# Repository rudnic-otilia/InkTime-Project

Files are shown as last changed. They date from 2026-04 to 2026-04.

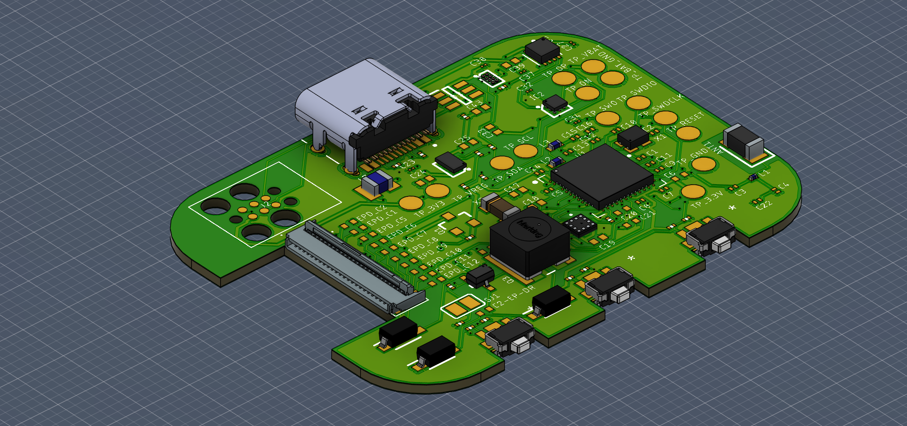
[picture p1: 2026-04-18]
Images/pcb.png

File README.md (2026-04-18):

# InkTime

Smartwatch open-source bazat pe nRF52840, cu display e-paper.

## Diagramă Bloc
Diagram

## BOM (Bill of Materials)

## Componente principale

| Referinta | Componenta | Descriere | Package | Cantitate | JLCPCB / LCSC | Datasheet |
|---|---|---|---|---|---|---|
| U1 | NRF52840-QIAA-R | MCU principal + BLE 5.0 + USB nativ | aQFN-73 (7×7mm) | 1 | [C190794](https://jlcpcb.com/partdetail/NordicSemicon-NRF52840_QIAAR/C190794) | [Datasheet](https://infocenter.nordicsemi.com/pdf/nRF52840_PS_v1.7.pdf) |
| IC1 | BQ25180YBGR | Charger LiPo cu power-path, I2C | DSBGA-8 (1.6×1.1mm) | 1 | [C3682423](https://jlcpcb.com/partdetail/TexasInstruments-BQ25180YBGR/C3682423) | [Datasheet](https://www.ti.com/lit/ds/symlink/bq25180.pdf) |
| IC9 | RT6160AWSC | Buck-boost regulator 3.3V, I2C | WLCSP-15 (1.4×2.3mm) | 1 | [C7065276](https://jlcpcb.com/partdetail/RichTek-RT6160AWSC/C7065276) | [Datasheet](https://www.richtek.com/assets/product_file/RT6160A/DS6160A-00.pdf) |
| U3 | MAX17048G+T10 | Fuel gauge baterie LiPo, I2C | DFN-8 (2×2mm) | 1 | [C2682616](https://jlcpcb.com/partdetail/MaximIntegrated-MAX17048GT10/C2682616) | [Datasheet](https://www.analog.com/media/en/technical-documentation/data-sheets/MAX17048-MAX17049.pdf) |
| IC3 | BMA423 | Accelerometru 3-axe + pedometru, I2C | LGA-12 (2×2mm) | 1 | [C189517](https://jlcpcb.com/partdetail/BoschSensortec-BMA423/C189517) | [Datasheet](https://www.lcsc.com/datasheet/C189517.pdf) |
| IC2 | DRV2605YZFR | Haptic driver pentru motor ERM, I2C | DSBGA-9 (1.44×1.44mm) | 1 | [C81079](https://jlcpcb.com/partdetail/TexasInstruments-DRV2605YZFR/C81079) | [Datasheet](https://www.ti.com/lit/ds/symlink/drv2605.pdf) |
| D3 | USBLC6-2SC6Y | Protecție ESD linii USB D+/D- | SOT-23-6 | 1 | [C5310974](https://jlcpcb.com/partdetail/TECHPUBLIC-USBLC62SC6Y/C5310974) | [Datasheet](https://www.st.com/resource/en/datasheet/usblc6-2.pdf) |
| Q3 | SI1308EDL-T1-GE3 | N-channel MOSFET, power gate e-paper | SC-70-3 | 1 | [C10487](https://jlcpcb.com/partdetail/VishayIntertech-SI1308EDLT1GE3/C10487) | [Datasheet](https://www.vishay.com/docs/63587/si1308edl.pdf) |
| Q1 | DMG2305UX-7 | P-channel MOSFET, power switch | SOT-23-3 | 1 | [C252544](https://jlcpcb.com/partdetail/Diodes-DMG2305UXT116/C252544) | [Datasheet](https://www.diodes.com/assets/Datasheets/DMG2305UX.pdf) |
| J4 | KH-TYPE-C-16P | Conector USB-C 16 pini | SMD | 1 | [C2765186](https://jlcpcb.com/partdetail/Kinghelm-KH_TYPEC_16P/C2765186) | [Datasheet](https://www.kinghelm.net/usb-connectors/kh-type-c-16p.html) |
| J1 | 503480-2400 | Conector FPC 0.5mm 24 pini, pentru display e-paper | SMD | 1 | [C262280](https://jlcpcb.com/partdetail/Molex-5034802400/C262280) | [Datasheet](https://www.molex.com/en-us/products/part-detail/503480-2400) |
| J2 | TC2030-IDC | Conector Tag-Connect SWD debug/programare | PCB footprint | 1 | — | [Datasheet](https://www.tag-connect.com/wp-content/uploads/bsk-pdf-manager/TC2030-IDC_1.pdf) |
| ANT1 | 2450AT18B100E | Antenă chip 2.4GHz pentru BLE | SMD | 1 | [C89771](https://jlcpcb.com/partdetail/Johanson-2450AT18B100E/C89771) | [Datasheet](https://www.johansontechnology.com/datasheets/2450AT18B100E/2450AT18B100E.pdf) |
| X1 | X322516MLB4SI | Crystal HFXO 32MHz, 8pF, ±10ppm pentru nRF52840 | SMD 2016 | 1 | [C13738](https://jlcpcb.com/partdetail/YangxingTech-X322516MLB4SI/C13738) | [Datasheet](https://datasheet.lcsc.com/lcsc/2110221730_YXC-X322516MLB4SI_C13738.pdf) |
| X2 | Q13FC13500004 | Crystal LFXO 32.768kHz, 12.5pF, ±20ppm pentru RTC | SMD 3215 | 1 | [C32346](https://jlcpcb.com/partdetail/Epson-Q13FC13500004/C32346) | [Datasheet](https://www.lcsc.com/datasheet/C32346.pdf) |
| SW_UP, SW_DN, SW_ENT | EVP-AKE31A | Butoane tactile SMD | SMD | 3 | [C3669064](https://jlcpcb.com/partdetail/Panasonic-EVPAKE31A/C3669064) | [Datasheet](https://industrial.panasonic.com/cdbs/www-data/pdf/ATV0000/ATV0000CE5.pdf) |
| D2, D4, D5 | MBR0530 | Diodă Schottky 0.5A 30V, circuit drive e-paper | SOD-123 | 3 | [C424058](https://jlcpcb.com/partdetail/onsemi-MBR0530T1G/C424058) | [Datasheet](https://www.onsemi.com/pdf/datasheet/mbr0530t1-d.pdf) |
| L7 | FTC252012SR47MBCA | Inductor 0.47µH pentru DC/DC | 0402 | 1 | [C408368](https://jlcpcb.com/partdetail/C408368) | — |
| L5 | Inductor 68µH | Inductor boost pentru circuit drive e-paper | SMD | 1 | — | — |

---

## Pasive (rezistențe și condensatoare)

| Referință | Valoare | Package | Cantitate | Notă |
|---|---|---|---|---|
| C1, C2, C17, C18 | 12pF | 0201 / 0402 | 4 | Load caps cristale |
| C3, C4 | 1pF | 0201 | 2 | RF matching |
| C5, C7, C8, C12, C19 | 100nF | 0201 / 0402 | 5 | Decoupling MCU |
| C6, C20, C21, C14, C43 | 4.7µF | 0402 | 5 | Bulk decoupling |
| C9 | 820pF | 0201 | 1 | RF matching |
| C11 | 100pF | 0201 | 1 | Decoupling |
| C15 | 1.0µF | 0201 | 1 | Decoupling |
| C16 | 47nF | 0201 | 1 | Decoupling |
| C24, C39 | 10µF | 0402 | 2 | Bulk decoupling |
| C25, C33 | 22µF | 0402 | 2 | Output caps RT6160 |
| C23, C27, C34, C32, C37, C38 | 0.1µF / 1µF | 0201 | 6 | Decoupling PMIC |
| C29, C30, C31, C42 | 1µF / 0.1µF | 0201 | 4 | Decoupling diverși |
| C1-EP-DR | 10µF | 0402 | 1 | Circuit drive EPD |
| C2-EP-DR | 4.7µF/25V | 0402 | 1 | Circuit drive EPD |
| EPD_C1...C12 | 1µF/50V, 0.1µF/50V | 0402 | 10 | Condensatoare display |
| R17, R18 | 3K3 | 0201 | 2 | Pull-up I2C |
| R5, R7, R8, R9, R_PWR_EPD, R2_EP_DR | 10K | 0201 | 6 | Pull-up / bias |
| R1_USB, R2_USB | 5K1 | 0201 | 2 | CC pins USB-C |
| R_TYPE_SEL | 2.2Ω | 0201 | 1 | Selecție tip charger |
| R1_EP_DR | 0.47Ω | 0201 | 1 | Sense rezistor EPD |
| R2, R3, R4 | 0Ω | 0201 | 3 | Jumperi / DNP |
| L1 | 3.9nH | 0201 | 1 | RF matching |
| L2 | 10µH | 0402 | 1 | DC/DC inductor MCU |
| L3 | 15nH | 0402 | 1 | RF matching |

---

# Descriere Hardware

## MCU — nRF52840

Microcontrollerul principal este nRF52840 de la Nordic Semiconductor, un ARM Cortex-M4 la 64 MHz cu BLE 5.0 si USB nativ integrate. Are 1 MB Flash si 256 KB RAM. A fost ales pentru ca include tot ce e necesar intr-un singur chip: procesor, radio BLE si USB, ceea ce simplifica mult designul unui smartwatch.

Are doua cristale externe obligatorii: unul de 32 MHz pentru BLE si USB, si unul de 32.768 kHz pentru ceasul in timp real (RTC) care mentine ora cand dispozitivul doarme.

Consumul in deep sleep este sub 2 uA, ceea ce il face potrivit pentru un dispozitiv cu baterie mica.

---

## Magistrala I2C

Majoritatea componentelor comunica cu MCU-ul prin I2C pe pinii P0.06 (SDA) si P0.07 (SCL), cu rezistente pull-up de 3.3K. Fiecare componenta are o adresa unica:

| Componenta | Rol | Adresa |
|---|---|---|
| BQ25180 | Charger baterie | 0x6A |
| RT6160 | Regulator 3.3V | 0x75 |
| MAX17048 | Nivel baterie | 0x36 |
| BMA423 | Accelerometru | 0x18 |
| DRV2605 | Motor vibratii | 0x5A |

---

## Display E-Paper

Display-ul de 1.54" (200x200 pixeli) este conectat prin SPI (SCK pe P0.02, MOSI pe P0.03, plus pini de control CS/DC/RST/BUSY). Avantajul e-paper-ului este ca nu consuma energie cand imaginea sta pe loc — consuma doar la refresh.

Alimentarea display-ului este controlata printr-un MOSFET (P1.01) care il opreste complet intre refresh-uri. Se face un refresh partial o data pe minut pentru a actualiza ora, si un full refresh mai rar pentru a elimina ghosting-ul.

---

## Alimentare

Lantul de alimentare functioneaza asa: USB-C (5V) → BQ25180 (incarca bateria si alimenteaza sistemul) → RT6160 (converteste tensiunea bateriei la 3.3V fix) → toate componentele.

BQ25180 are un circuit de power-path, adica sistemul functioneaza si fara baterie daca e conectat la USB. MAX17048 masoara nivelul bateriei si trimite o intrerupere la MCU cand bateria e aproape descarcata.

Pe liniile USB exista o dioda ESD (USBLC6-2SC6Y) care protejeaza circuitul impotriva descarcarilor electrostatice.

---

## Senzori si periferice

**BMA423** — accelerometru cu pedometru hardware integrat. Numara pasii independent, fara sa trezeasca MCU-ul. Trezeste MCU-ul printr-o intrerupere pe P0.08 cand detecteaza miscare sau un anumit numar de pasi.

**DRV2605** — driver pentru motorul de vibratie. MCU-ul ii trimite prin I2C un ID de efect, iar DRV2605 il executa autonom din biblioteca sa de 123 de efecte stocate intern.

**Butoane** — trei butoane (Sus/Jos/Enter) conectate active-low la GND pe pinii P0.13, P0.14 si P1.00. Pot trezi MCU-ul din sleep.

---

## Consum estimat

| Stare | Curent | Timp/zi |
|---|---|---|
| Deep sleep | ~8 uA | ~24h |
| Refresh display (1x/min) | ~8 mA | ~60s total |
| Notificare (BLE + display + vibratii) | ~15 mA | ~100s total |

Total estimat: ~2 mAh/zi → pe o baterie de 250 mAh rezulta o autonomie teoretica de peste 100 de zile. In practica, cu pierderile reale, targetul este de 30 de zile conform specificatiilor proiectului.

# Pini nRF52840 folositi

## I2C — P0.06 (SDA) si P0.07 (SCL)

Acesti doi pini sunt folositi de toate componentele care comunica prin I2C: charger-ul BQ25180,
regulatorul RT6160, fuel gauge-ul MAX17048, accelerometrul BMA423 si driverul haptic DRV2605.
Sunt pini de uz general cu suport hardware I2C si sunt plasati convenabil in schema pentru
rutarea PCB-ului. Pull-up-urile de 3.3K sunt necesare pentru ca I2C are iesiri open-drain.

## SPI — P0.02 (SCK), P0.03 (MOSI), P0.05 (CS)

Folositi pentru comunicatia cu display-ul e-paper. SPI a fost ales in loc de I2C pentru display
deoarece este mult mai rapid, important la refresh-ul imaginii. CS (chip select) pe P0.05
activeaza display-ul doar cand MCU-ul vrea sa ii trimita date.

## Pini de control display — P0.15 (DC), P0.16 (RST), P0.17 (BUSY)

- **DC** (Data/Command): ii spune display-ului daca ce primeste este o comanda sau date de imagine
- **RST** (Reset): reseteaza display-ul la pornire sau dupa o eroare
- **BUSY**: display-ul tine acest pin activ cat timp proceseaza un refresh; MCU-ul asteapta sa
  se elibereze inainte sa trimita date noi

## Power gate display — P1.01

Controleaza MOSFET-ul care opreste alimentarea display-ului cand nu e folosit. Implicit OFF la
reset, activat doar in timpul unui refresh. Economiseste energie intre actualizari.

## Intreruperi

- **P0.08 — BMA423 INT1**: trezeste MCU-ul din deep sleep la detectia de miscare sau pas.
  Folosit ca sursa principala de wake-up pentru activitate fizica.
- **P1.08 — BMA423 INT2**: intrerupere secundara pentru evenimente avansate ale accelerometrului.
- **P0.10 — MAX17048 ALRT**: MCU-ul este notificat cand bateria scade sub un prag configurat,
  pentru a afisa avertismentul de baterie descarcata.
- **P0.11 — BQ25180 /INT**: notifica MCU-ul la evenimente de incarcare (USB conectat/deconectat,
  incarcare completa, eroare).

## Haptic enable — P0.12

Controleaza pinul EN al DRV2605. Cand nu e niciun eveniment haptic, acest pin e LOW si driverul
consuma sub 1 uA. MCU-ul il ridica la HIGH doar inainte sa trimita o comanda de vibratie.

## Butoane — P0.13, P0.14, P1.00

- **P0.13** — buton Sus
- **P0.14** — buton Jos
- **P1.00** — buton Enter / Esc

Toti trei sunt configurati cu pull-up intern si wake-on-low, adica o apasare de buton trezeste
MCU-ul direct din deep sleep fara consum suplimentar.

## USB — USBDP / USBDM (D+ / D-)

Pini dedicati USB ai nRF52840, rutati diferential la conectorul USB-C prin dioda ESD. Folositi
pentru programarea firmware-ului si optional pentru comunicatie cu PC-ul.

## SWD — SWDIO, SWDCLK, nRESET

Pini dedicati de debug si programare, conectati la conectorul TC2030. Folositi cu un programator
J-Link pentru a incarca firmware-ul si pentru debugging in timp real.

# Design Decisions — DRC Approved Errors

DRC-ul a returnat 0 erori si 85 aprobate. Motivele aprobarii:

- **Overlap (35) si Board Outline Clearance (40)**: provin din pozitia butoanelor, care a fost
  stabilita ca cerinta de proiect si nu poate fi modificata.

- **Copper Clearance (9)**: vias-uri care se intersecteaza

- **Copper - Restrict Clearance (1)**: zona restrictionata definita intentionat in jurul antenei
  BLE pentru izolarea ground plane-ului, conform recomandarilor Nordic Semiconductor.

Apache 2.0 — vezi [LICENSE](LICENSE)

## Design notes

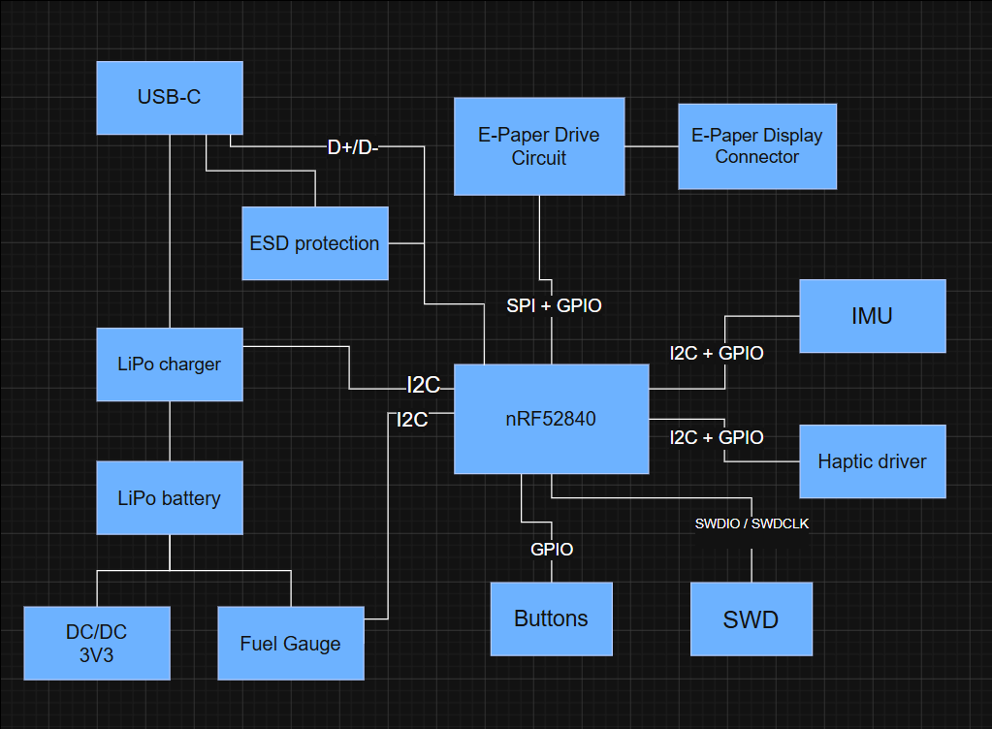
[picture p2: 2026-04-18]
Images/Diagram.png

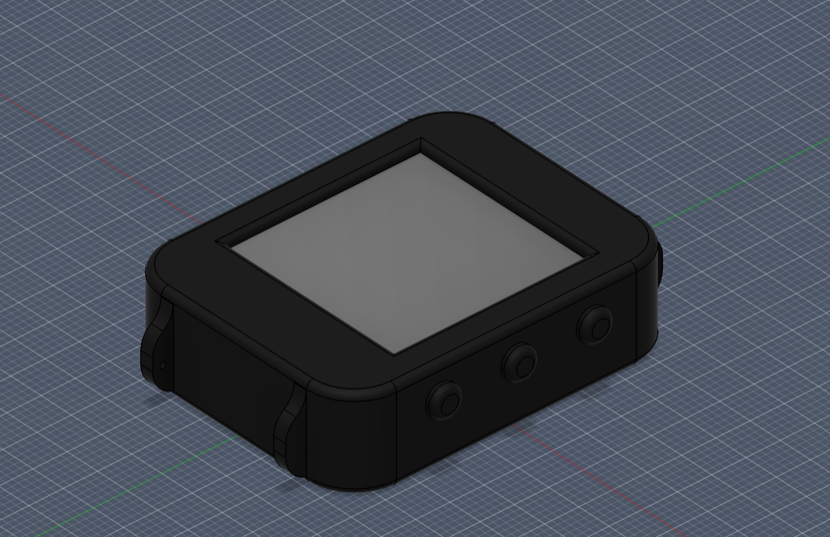
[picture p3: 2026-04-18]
Images/case.png

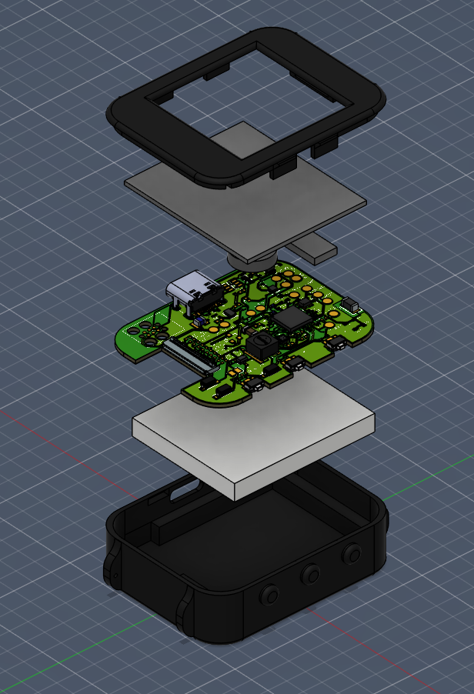
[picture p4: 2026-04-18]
Images/case-exploded-view.png

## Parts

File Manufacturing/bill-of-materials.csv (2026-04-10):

Reference Designators | Quantity | Description | Package | Value | Manufacturer | Manufacturer Part Number | Vendor | Vendor Part Number | Top/Bottom
 | 1 | PCB Board | Board
ANT1 | 1 | Antennas 2.45GHz ANTENNA | 2450AT18B100E_ANTC3216X140N | 2450AT18B100E |  |  |  |  | Top
C1, C2 | 2 | Generic chip capacitor | NORDIC_NRF_3_RESC0201_L | 12pF |  |  |  |  | Top
C1-EP-DR | 1 | Generic chip capacitor | NORDIC_NRF_3_RESC0402_L | 10uF |  |  |  |  | Top
C2-EP-DR | 1 | Generic chip capacitor | NORDIC_NRF_3_RESC0402_L | 4.7uF/25V |  |  |  |  | Top
C3, C4 | 2 | Generic chip capacitor | NORDIC_NRF_3_RESC0201_L | 1pF |  |  |  |  | Top
C5, C7, C8, C12 | 4 | Generic chip capacitor | NORDIC_NRF_3_RESC0201_L | 100nF |  |  |  |  | Top
C6, C20, C21 | 3 | Generic chip capacitor | NORDIC_NRF_3_RESC0402_L | 4.7uF |  |  |  |  | Top
C9 | 1 | Generic chip capacitor | NORDIC_NRF_3_RESC0201_L | 820pF |  |  |  |  | Top
C10, C13, C22 | 3 | Generic chip capacitor | NORDIC_NRF_3_RESC0201_L | N.C. |  |  |  |  | Top
C11 | 1 | Generic chip capacitor | NORDIC_NRF_3_RESC0201_L | 100pF |  |  |  |  | Top
C14 | 1 | Generic chip capacitor | NORDIC_NRF_3_RESC0201_L | 4.7uF |  |  |  |  | Top
C15 | 1 | Generic chip capacitor | NORDIC_NRF_3_RESC0201_L | 1.0uF |  |  |  |  | Top
C16 | 1 | Generic chip capacitor | NORDIC_NRF_3_RESC0201_L | 47nF |  |  |  |  | Top
C17, C18 | 2 | 0402 (1005 Metric) | PERFECT_0402_0402 | 12pF |  |  |  |  | Top
C19 | 1 | 0402 (1005 Metric) | PERFECT_0402_0402 | 100nF |  |  |  |  | Top
C23, C27, C34 | 3 | Check availability | CAPC0201X13N | 0.1uF |  |  |  |  | Top
C24, C39 | 2 | 0402 (1005 Metric) | PERFECT_0402_0402 | 10uF |  |  |  |  | Top
C25, C33 | 2 | 0402 (1005 Metric) | PERFECT_0402_0402 | 22uF |  |  |  |  | Top
C29, C30, C31 | 3 | Check availability | GRM011R60J152KE01L_1_0201 | 1uF |  |  |  |  | Top
C32, C37, C38 | 3 | Check availability | CAPC0201X13N | 1uF |  |  |  |  | Top
C42 | 1 | Check availability | GRM011R60J152KE01L_1_0201 | 0.1uF |  |  |  |  | Top
C43 | 1 | 0402 (1005 Metric) | PERFECT_0402_0402 | 4.7uF |  |  |  |  | Top
D2, D4, D5 | 3 | ON SEMICONDUCTOR - MBR0530 - DIODE, SCHOTTKY, 0.5A, 30V, SOD-123 | SOD3716X135N | MBR0530 |  |  |  |  | Top
D3 | 1 | Low Cap. ESD Protection Auto SOT-23-6 STMicroelectronics USBLC6-2SC6Y, Dual Uni-Directional TVS Diode Array, 6-Pin SOT-23 | SOT95P280X145-6N | USBLC6-2SC6Y |  |  |  |  | Top
EPD_C1, EPD_C2, EPD_C6, EPD_C7, EPD_C8, EPD_C9, EPD_C10, EPD_C11, EPD_C12 | 9 | Generic chip capacitor | NORDIC_NRF_3_RESC0402_L | 1uF/50V |  |  |  |  | Top
EPD_C5 | 1 | Generic chip capacitor | NORDIC_NRF_3_RESC0402_L | 0.1uF/50V |  |  |  |  | Top
IC1 | 1 | Charger IC Lithium Ion/Polymer, Lithium Iron Phosphate 8-DSBGA (1.6x1.1) | BQ25180YBGR_BGA8C40P2X4_100X155X50 | BQ25180YBGR |  |  |  |  | Top
IC2 | 1 | Haptic Driver for ERM/LRA with Built-In Library and Smart Loop Architecture | DRV2605YZFR_BGA9C50P3X3_144X144X62 | DRV2605YZFR |  |  |  |  | Top
IC3 | 1 | Accelerometers Triaxial low-g 12bit Acceleration Sensor | BMA423_BMA423 | BMA423 |  |  |  |  | Top
IC9 | 1 | Buck-Boost Regulator Positive Output Step-Up/Step-Down I2C DC-DC Controller IC 15-WL-CSP (BSC) (1.4x2.3) | RT6160AWSC_BGA15C40P3X5_140X230X60 | RT6160AWSC |  |  |  |  | Top
J1 | 1 | FFC & FPC Connectors 0.5mm FPC RA SMT Dual Contact 24Ckt | 503480-2400_5034802400 | 503480-2400 |  |  |  |  | Top
J2 | 1 | CABLE ADAPTER 6 POS | TC2030-IDC_TC2030IDC | TC2030-IDC |  |  |  |  | Top
J4 | 1 | Check availability | KINGHELM_KH-TYPE-C-16P | KH-TYPE-C-16P |  |  |  |  | Top
L1 | 1 | Generic chip inductor | NORDIC_NRF_2_RESC0201_L | 3.9nH |  |  |  |  | Top
L2 | 1 | Generic chip inductor | NORDIC_NRF_2_RESC0402_L | 10uH |  |  |  |  | Top
L3 | 1 | Generic chip inductor | NORDIC_NRF_2_RESC0402_L | 15nH |  |  |  |  | Top
L5 | 1 |  | ESP32_C6_LIBRARY_2_IND_4828-WE-TPC_WRE | 68uH |  |  |  |  | Top
L7 | 1 | SMD / SMT Inductors (Coils), L=0.47?H, L x W x T : | MLP2016SR47MT0S1_INDC2016X100N | FTC252012SR47MBCA |  |  |  |  | Top
Q1 | 1 | P-channel MOSFETs | ESP32_WROVER_SPARKFUN-DISCRETESEMI_SOT23-3 | 20V/4.2A/52mΩ/1.4W |  |  |  |  | Top
Q3 | 1 | MOSFET N-Ch 30V 1.5A TrenchFET SC70 Vishay Si1308EDL-T1-GE3 N-channel MOSFET Transistor, 1.5 A, 30 V, 3-Pin SC-70 | SOT65P210X110-3N | SI1308EDL-T1-GE3 |  |  |  |  | Top
R_PWR_EPD, R2_EP_DR, R5, R7, R8, R9 | 6 | 7.68k 0201 Thin Film Surface Mount Fixed Resistor +/-0.5% 0.031W CPF0201D7K68C1 | CPF0201D7K68C1_0201 | 10K |  |  |  |  | Top
R_TYPE_SEL | 1 | 7.68k 0201 Thin Film Surface Mount Fixed Resistor +/-0.5% 0.031W CPF0201D7K68C1 | CPF0201D7K68C1_0201 | 2.2 |  |  |  |  | Top
R1_EP_DR | 1 | 7.68k 0201 Thin Film Surface Mount Fixed Resistor +/-0.5% 0.031W CPF0201D7K68C1 | CPF0201D7K68C1_0201 | 0.47 |  |  |  |  | Top
R1_USB, R2_USB | 2 | 7.68k 0201 Thin Film Surface Mount Fixed Resistor +/-0.5% 0.031W CPF0201D7K68C1 | CPF0201D7K68C1_0201 | 5K1 |  |  |  |  | Top
R2, R4 | 2 | 7.68k 0201 Thin Film Surface Mount Fixed Resistor +/-0.5% 0.031W CPF0201D7K68C1 | R0201 | 0 |  |  |  |  | Top
R3 | 1 | 7.68k 0201 Thin Film Surface Mount Fixed Resistor +/-0.5% 0.031W CPF0201D7K68C1 | CPF0201D7K68C1_0201 | 0 |  |  |  |  | Top
R17, R18 | 2 | 7.68k 0201 Thin Film Surface Mount Fixed Resistor +/-0.5% 0.031W CPF0201D7K68C1 | CPF0201D7K68C1_0201 | 3K3 |  |  |  |  | Top
SJ1 | 1 | SMD solder JUMPER | JUMPER_SJ |  |  |  |  |  | Top
SW_DN, SW_ENT, SW_UP | 3 |  | SW_EVP-AKE31A_PAN | 2025-10-22_07-23-44_LIBRARY_EVP-AKE31ASW_EVP-AKE31A_PAN |  |  |  |  | Top
TP_3.3V, TP_3V3, TP_BAT_GND, TP_GND, TP_ON, TP_OP, TP_RESET, TP_SCL, TP_SDA, TP_SWDCLK, TP_SWDIO, TP_SWO, TP_VBAT, TP_VREG | 14 | Test pad | HECTOR_WATCH_1_TP20R | HECTOR_WATCH_1_TPTP20R |  |  |  |  | Top
U1 | 1 | nRF52840 | NORDIC_NRF_4_AQFN50P700X700X85_HS-74N | NRF52840_QF |  |  |  |  | Top
U3 | 1 | Check availability | SON50P200X200X80-9N | MAX17048G+T10 |  |  |  |  | Top
X1 | 1 |  | NORDIC_NRF_BT-XTAL_2016_N | 32MHZ |  |  |  |  | Top
X2 | 1 |  | NORDIC_NRF_1_XTAL_3215_N | 32.768kHz |  |  |  |  | Top

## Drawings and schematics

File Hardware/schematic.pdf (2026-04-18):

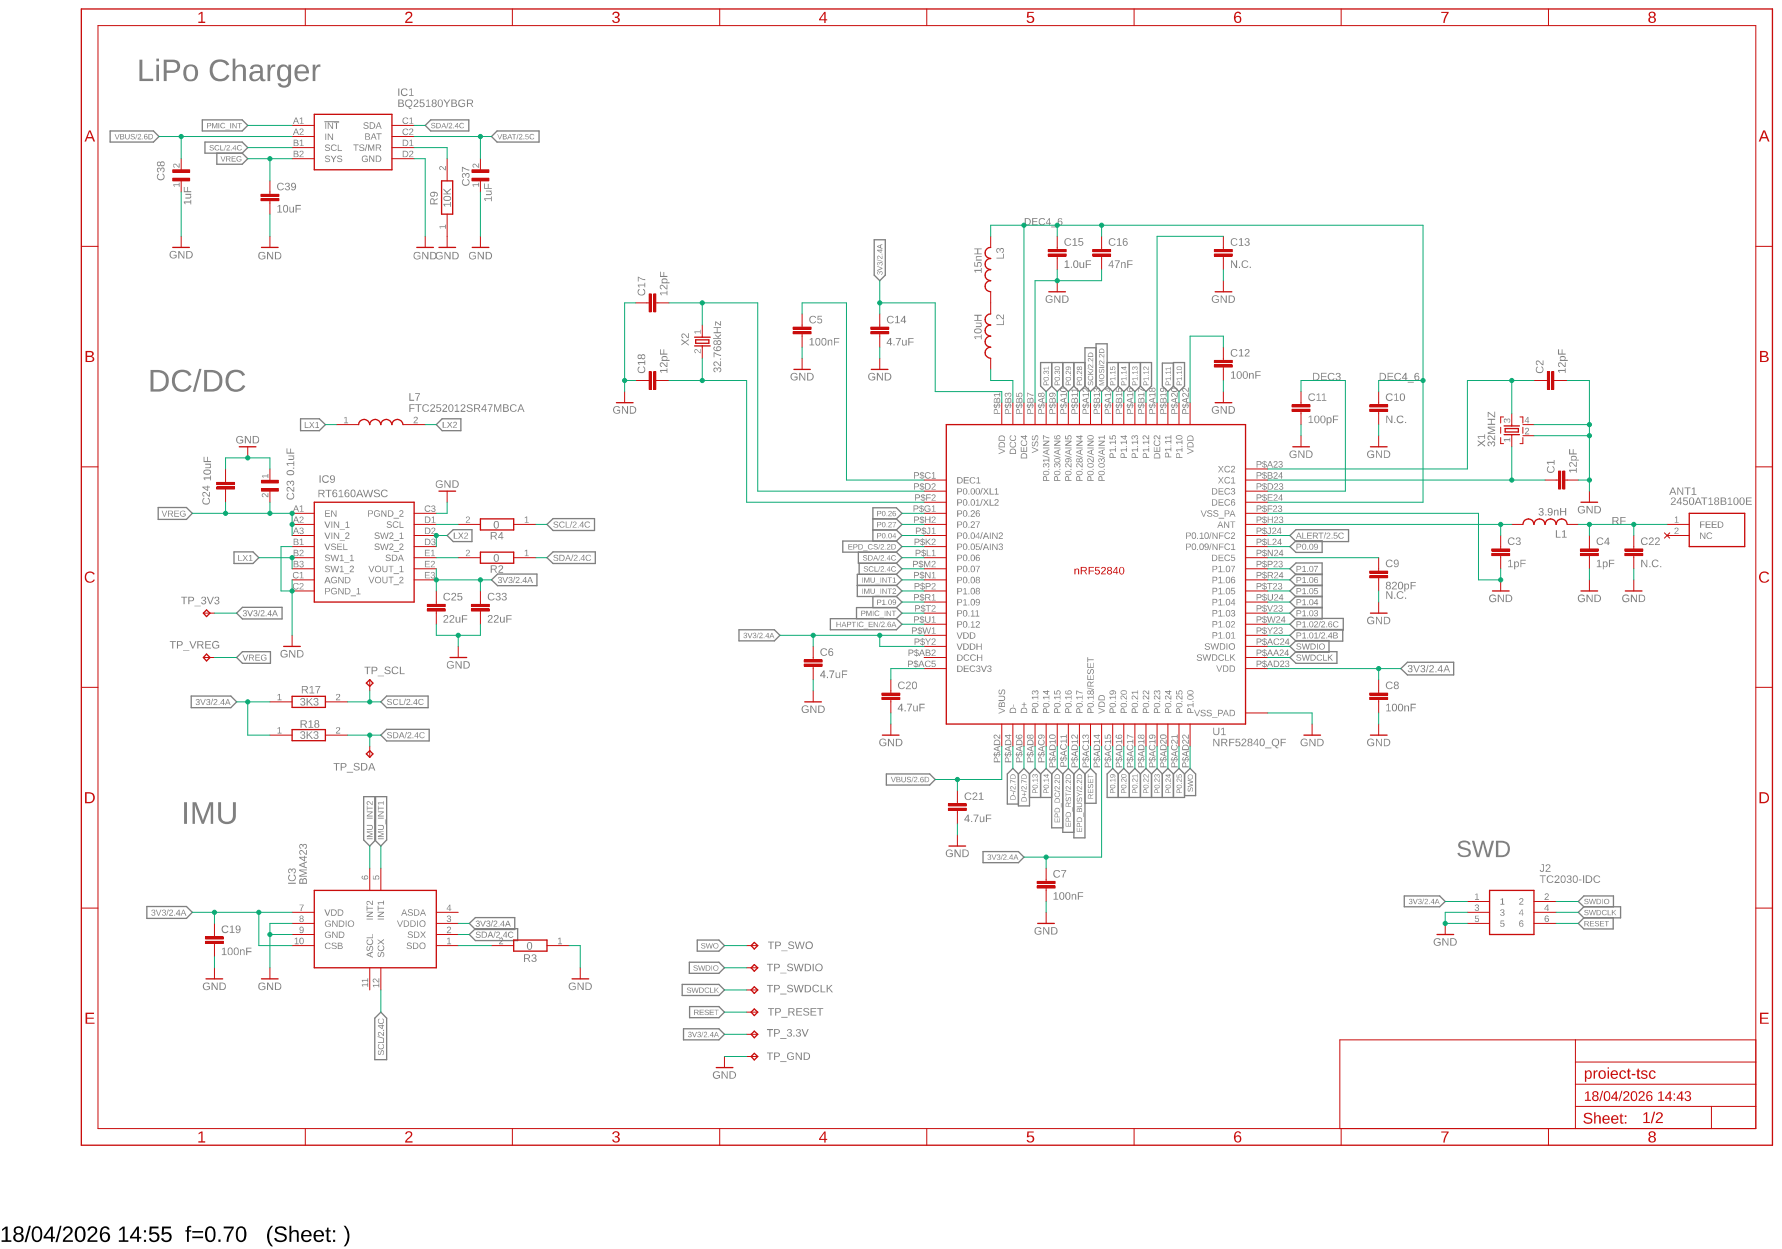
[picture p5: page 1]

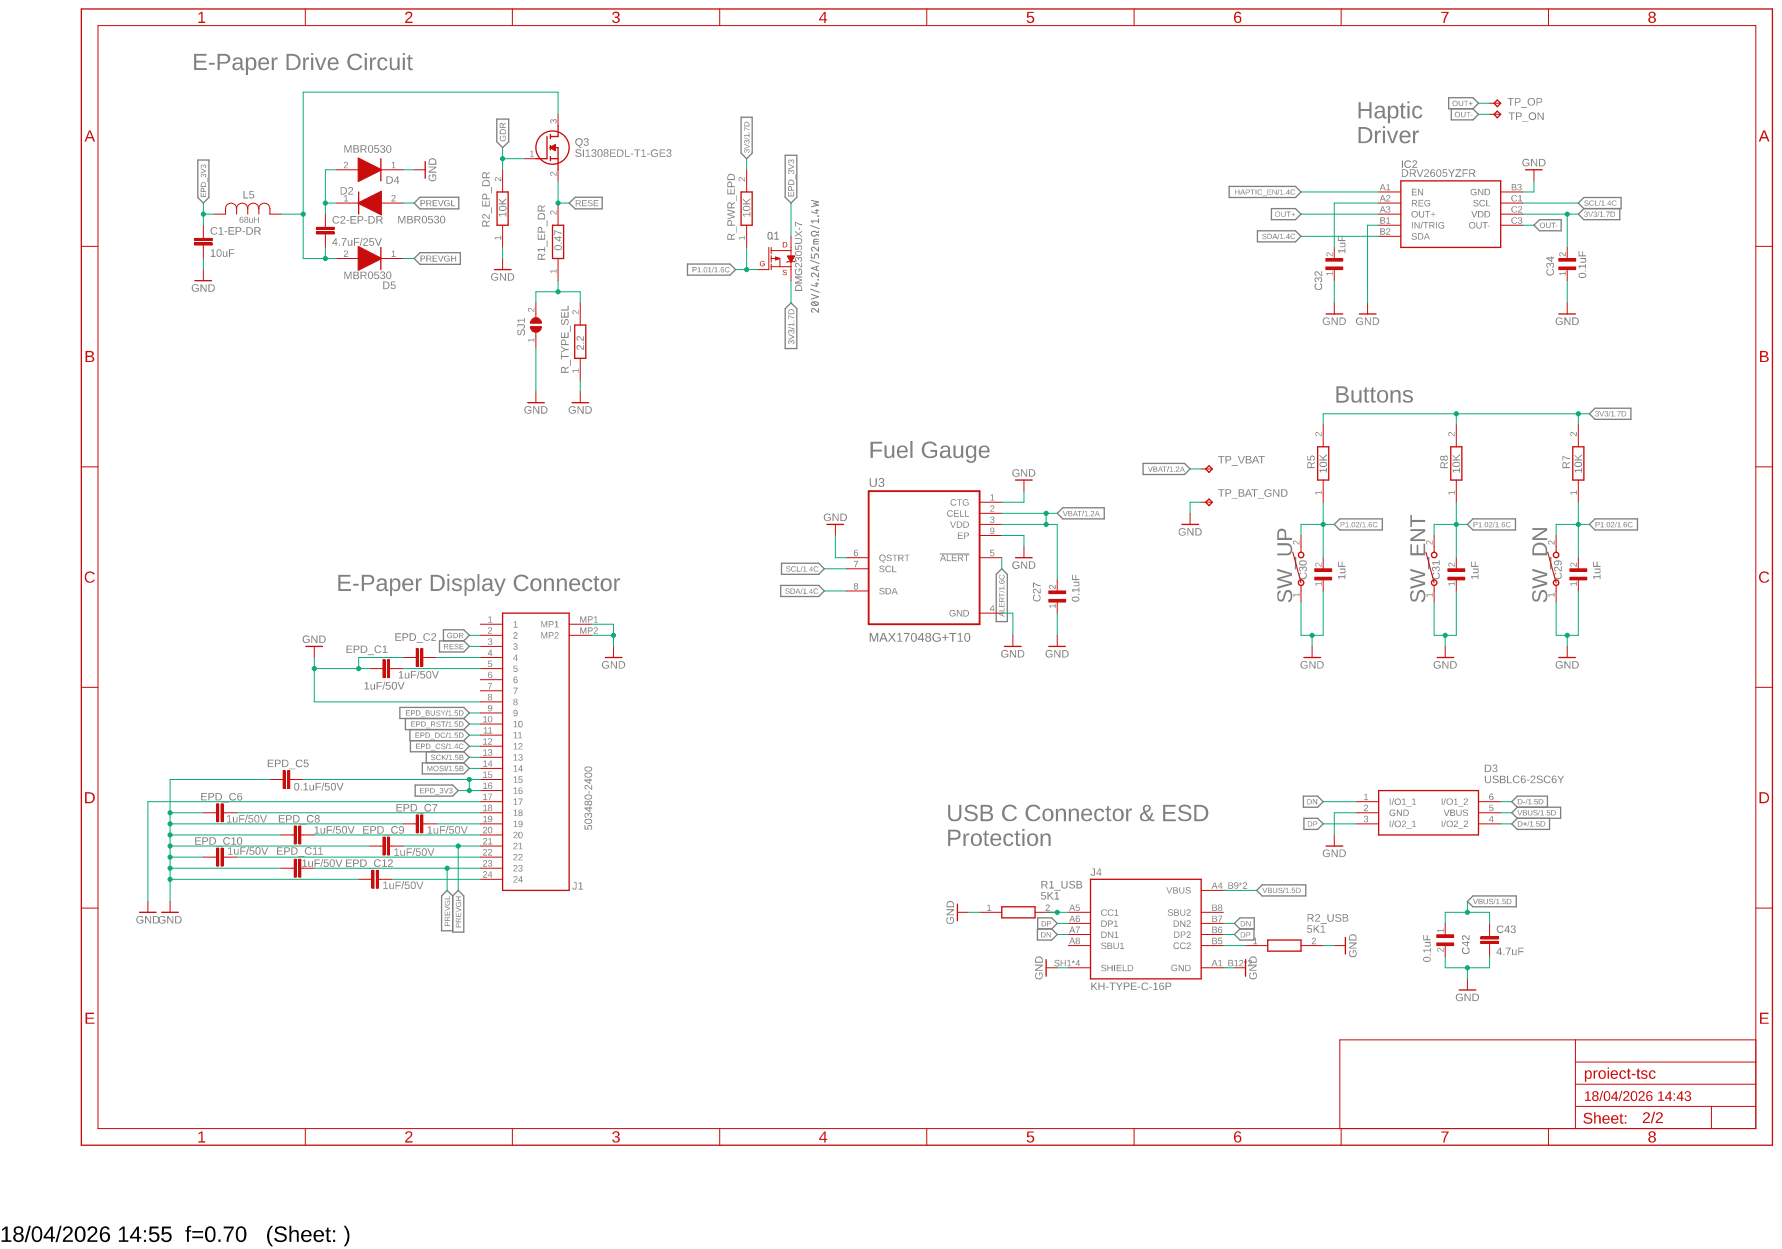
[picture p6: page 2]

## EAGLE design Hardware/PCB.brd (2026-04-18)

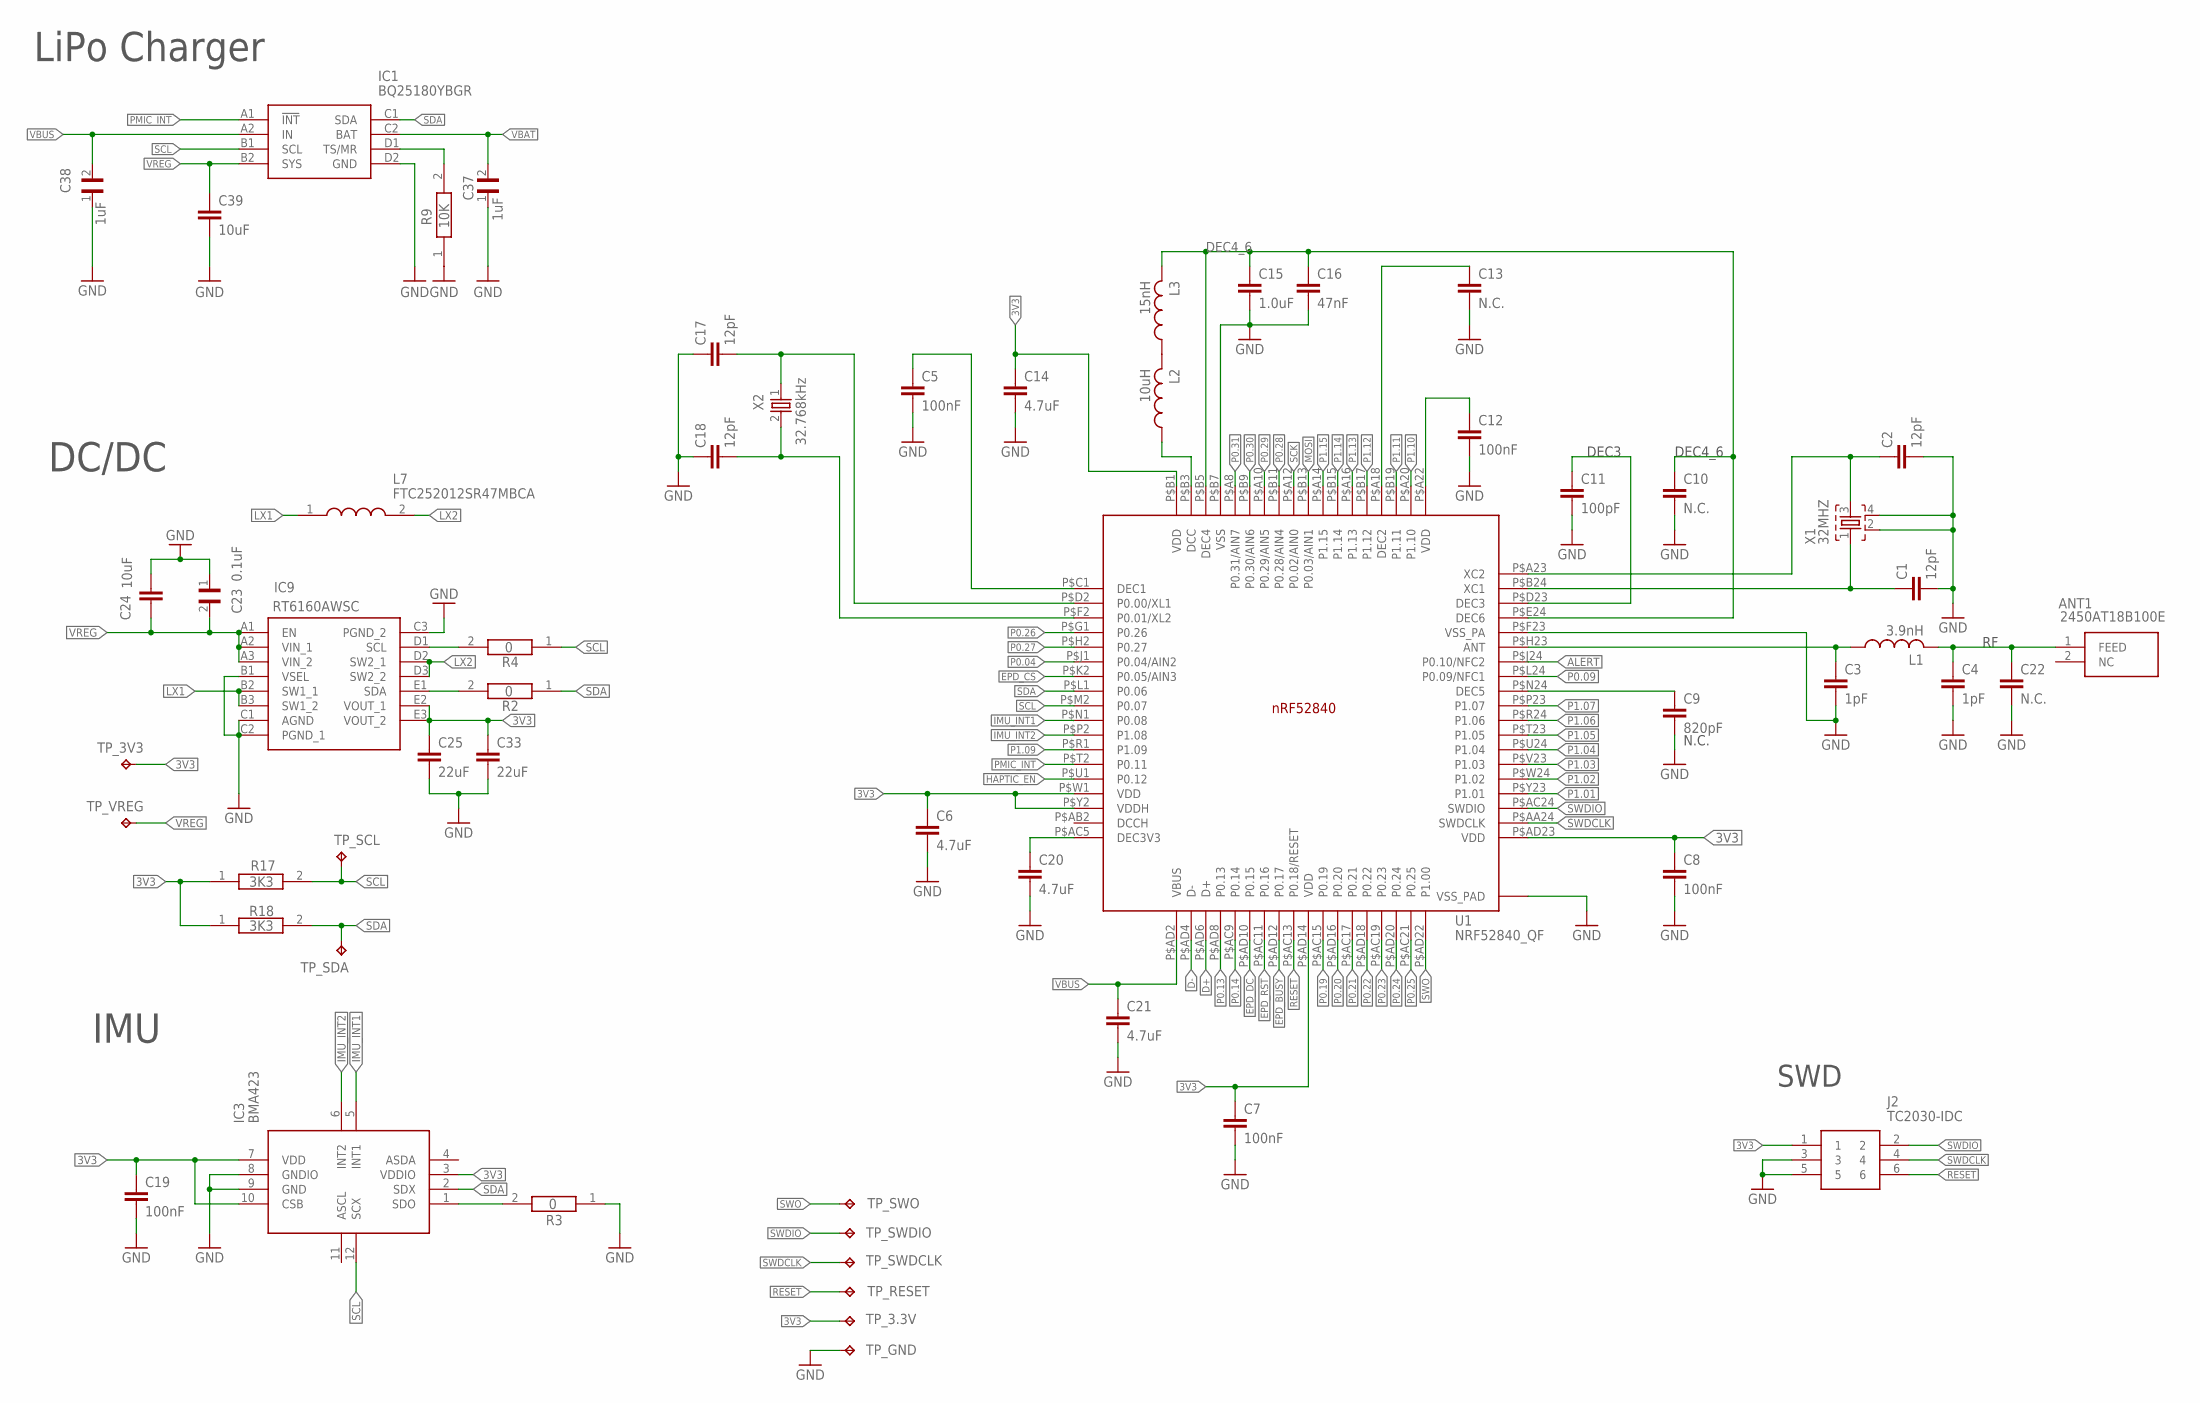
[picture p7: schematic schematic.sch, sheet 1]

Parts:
ANT1: 2450AT18B100E; 2450AT18B100E_ANTC3216X140N
C1, C2: 12pF; NORDIC_NRF_3_RESC0201_L
C3, C4: 1pF; NORDIC_NRF_3_RESC0201_L
C5, C7, C8, C12: 100nF; NORDIC_NRF_3_RESC0201_L
C6, C20, C21: 4.7uF; NORDIC_NRF_3_RESC0402_L
C9: 820pF; NORDIC_NRF_3_RESC0201_L
C10, C13, C22: N.C.; NORDIC_NRF_3_RESC0201_L
C11: 100pF; NORDIC_NRF_3_RESC0201_L
C14: 4.7uF; NORDIC_NRF_3_RESC0201_L
C15: 1.0uF; NORDIC_NRF_3_RESC0201_L
C16: 47nF; NORDIC_NRF_3_RESC0201_L
C17, C18: 12pF; PERFECT_0402_0402
C19: 100nF; PERFECT_0402_0402
C23: 0.1uF; GRM011R60J152KE01L_2_CAPC0201X13N
C24, C39: 10uF; PERFECT_0402_0402
C25, C33: 22uF; PERFECT_0402_0402
C37, C38: 1uF; GRM011R60J152KE01L_2_CAPC0201X13N
IC1: BQ25180YBGR; BQ25180YBGR_BGA8C40P2X4_100X155X50
IC3: BMA423; BMA423_BMA423
IC9: RT6160AWSC; RT6160AWSC_BGA15C40P3X5_140X230X60
J2: TC2030-IDC; TC2030-IDC_TC2030IDC
L1: 3.9nH; NORDIC_NRF_2_RESC0201_L
L2: 10uH; NORDIC_NRF_2_RESC0402_L
L3: 15nH; NORDIC_NRF_2_RESC0402_L
L7: FTC252012SR47MBCA; MLP2016SR47MT0S1_INDC2016X100N
R2, R4: 0; ERA-1AEB3401C_0201
R3: 0; CPF0201D7K68C1_0201
R9: 10K; CPF0201D7K68C1_0201
R17, R18: 3K3; CPF0201D7K68C1_0201
TP_3.3V, TP_3V3: HECTOR_WATCH_1_TPTP20R; HECTOR_WATCH_1_TP20R
TP_GND: HECTOR_WATCH_1_TPTP20R; HECTOR_WATCH_1_TP20R
TP_RESET: HECTOR_WATCH_1_TPTP20R; HECTOR_WATCH_1_TP20R
TP_SCL: HECTOR_WATCH_1_TPTP20R; HECTOR_WATCH_1_TP20R
TP_SDA: HECTOR_WATCH_1_TPTP20R; HECTOR_WATCH_1_TP20R
TP_SWDCLK: HECTOR_WATCH_1_TPTP20R; HECTOR_WATCH_1_TP20R
TP_SWDIO: HECTOR_WATCH_1_TPTP20R; HECTOR_WATCH_1_TP20R
TP_SWO: HECTOR_WATCH_1_TPTP20R; HECTOR_WATCH_1_TP20R
TP_VREG: HECTOR_WATCH_1_TPTP20R; HECTOR_WATCH_1_TP20R
U1: NRF52840_QF; NORDIC_NRF_4_AQFN50P700X700X85_HS-74N
X1: 32MHZ; NORDIC_NRF_BT-XTAL_2016_N
X2: 32.768kHz; NORDIC_NRF_1_XTAL_3215_N

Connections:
3V3: C6.1, C7.1, C8.1, C14.1, C19.1, C25.1, C33.1, IC3.3 (VDDIO), IC3.7 (VDD), IC3.10 (CSB), IC9.E2 (VOUT_1), IC9.E3 (VOUT_2), J2.1, R17.1, R18.1, TP_3.3V.TP, TP_3V3.TP, U1.P$AD14 (VDD), U1.P$AD23 (VDD), U1.P$B1 (VDD), U1.P$W1 (VDD), U1.P$Y2 (VDDH); also elsewhere on the board
ALERT: U1.P$J24 (P0.10/NFC2); also elsewhere on the board
D+: U1.P$AD6 (D+); also elsewhere on the board
D-: U1.P$AD4 (D-); also elsewhere on the board
DEC4_6: C10.1, C15.1, C16.1, L3.2, U1.P$B5 (DEC4), U1.P$E24 (DEC6)
EPD_BUSY: U1.P$AD12 (P0.17); also elsewhere on the board
EPD_CS: U1.P$K2 (P0.05/AIN3); also elsewhere on the board
EPD_DC: U1.P$AD10 (P0.15); also elsewhere on the board
EPD_RST: U1.P$AC11 (P0.16); also elsewhere on the board
GND: C1.2, C2.2, C3.2, C4.2, C5.2, C6.2, C7.2, C8.2, C9.2, C10.2, C11.2, C12.2, C13.2, C14.2, C15.2, C16.2, C17.1, C18.1, C19.2, C20.2, C21.2, C22.2, C23.1, C24.1, C25.2, C33.2, C37.1, C38.1, C39.2, IC1.D2 (GND), IC3.8 (GNDIO), IC3.9 (GND), IC9.B1 (VSEL), IC9.C1 (AGND), IC9.C2 (PGND_1), IC9.C3 (PGND_2), J2.3, J2.5, R3.1, R9.1, TP_GND.TP, U1.P$74 (VSS_PAD), U1.P$75 (VSS_PAD), U1.P$76 (VSS_PAD), U1.P$77 (VSS_PAD), U1.P$78 (VSS_PAD), U1.P$79 (VSS_PAD), U1.P$80 (VSS_PAD), U1.P$81 (VSS_PAD), U1.P$82 (VSS_PAD), U1.P$83 (VSS_PAD), U1.P$84 (VSS_PAD), U1.P$85 (VSS_PAD), U1.P$86 (VSS_PAD), U1.P$87 (VSS_PAD), U1.P$88 (VSS_PAD), U1.P$89 (VSS_PAD), U1.P$90 (VSS_PAD), U1.P$B7 (VSS), U1.P$F23 (VSS_PA), X1.2, X1.4; also elsewhere on the board
HAPTIC_EN: U1.P$U1 (P0.12); also elsewhere on the board
IMU_INT1: IC3.5 (INT1), U1.P$N1 (P0.08)
IMU_INT2: IC3.6 (INT2), U1.P$P2 (P1.08)
LX1: IC9.B2 (SW1_1), IC9.B3 (SW1_2), L7.1
LX2: IC9.D2 (SW2_1), IC9.D3 (SW2_2), L7.2
MOSI: U1.P$B13 (P0.03/AIN1); also elsewhere on the board
unnamed: IC1.D1 (TS/MR), R9.2
unnamed: C11.1, U1.P$D23 (DEC3)
unnamed: IC9.D1 (SCL), R4.2
unnamed: IC9.E1 (SDA), R2.2
unnamed: C18.2, U1.P$F2 (P0.01/XL2), X2.2
unnamed: C17.2, U1.P$D2 (P0.00/XL1), X2.1
unnamed: IC3.1 (SDO), R3.2
unnamed: C5.1, U1.P$C1 (DEC1)
unnamed: L2.1, U1.P$B3 (DCC)
unnamed: L2.2, L3.1
unnamed: C12.1, U1.P$A22 (VDD)
unnamed: C13.1, U1.P$A18 (DEC2)
unnamed: C2.1, U1.P$A23 (XC2), X1.3
unnamed: C1.1, U1.P$B24 (XC1), X1.1
unnamed: C3.1, L1.1, U1.P$H23 (ANT)
unnamed: ANT1.1 (FEED), C4.1, C22.1, L1.2
unnamed: C9.1, U1.P$N24 (DEC5)
unnamed: C20.1, U1.P$AC5 (DEC3V3)
P0.04: U1.P$J1 (P0.04/AIN2)
P0.09: U1.P$L24 (P0.09/NFC1)
P0.13: U1.P$AD8 (P0.13)
P0.14: U1.P$AC9 (P0.14)
P0.19: U1.P$AC15 (P0.19)
P0.20: U1.P$AD16 (P0.20)
P0.21: U1.P$AC17 (P0.21)
P0.22: U1.P$AD18 (P0.22)
P0.23: U1.P$AC19 (P0.23)
P0.24: U1.P$AD20 (P0.24)
P0.25: U1.P$AC21 (P0.25)
P0.26: U1.P$G1 (P0.26)
P0.27: U1.P$H2 (P0.27)
P0.28: U1.P$B11 (P0.28/AIN4)
P0.29: U1.P$A10 (P0.29/AIN5)
P0.30: U1.P$B9 (P0.30/AIN6)
P0.31: U1.P$A8 (P0.31/AIN7)
P1.01: U1.P$Y23 (P1.01); also elsewhere on the board
P1.02: U1.P$W24 (P1.02); also elsewhere on the board
P1.03: U1.P$V23 (P1.03)
P1.04: U1.P$U24 (P1.04)
P1.05: U1.P$T23 (P1.05)
P1.06: U1.P$R24 (P1.06)
P1.07: U1.P$P23 (P1.07)
P1.09: U1.P$R1 (P1.09)
P1.10: U1.P$A20 (P1.10)
P1.11: U1.P$B19 (P1.11)
P1.12: U1.P$B17 (P1.12)
P1.13: U1.P$A16 (P1.13)
P1.14: U1.P$B15 (P1.14)
P1.15: U1.P$A14 (P1.15)
PMIC_INT: IC1.A1 (!INT), U1.P$T2 (P0.11)
RESET: J2.6, TP_RESET.TP, U1.P$AC13 (P0.18/RESET)
SCK: U1.P$A12 (P0.02/AIN0); also elsewhere on the board
SCL: IC1.B1 (SCL), IC3.12 (SCX), R4.1, R17.2, TP_SCL.TP, U1.P$M2 (P0.07); also elsewhere on the board
SDA: IC1.C1 (SDA), IC3.2 (SDX), R2.1, R18.2, TP_SDA.TP, U1.P$L1 (P0.06); also elsewhere on the board
SWDCLK: J2.4, TP_SWDCLK.TP, U1.P$AA24 (SWDCLK)
SWDIO: J2.2, TP_SWDIO.TP, U1.P$AC24 (SWDIO)
SWO: TP_SWO.TP, U1.P$AD22 (P1.00)
VBAT: C37.2, IC1.C2 (BAT); also elsewhere on the board
VBUS: C21.1, C38.2, IC1.A2 (IN), U1.P$AD2 (VBUS); also elsewhere on the board
VREG: C23.2, C24.2, C39.1, IC1.B2 (SYS), IC9.A1 (EN), IC9.A2 (VIN_1), IC9.A3 (VIN_2), TP_VREG.TP

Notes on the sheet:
LiPo Charger
DC/DC
IMU
DEC3
DEC4_6
N.C.
SWD

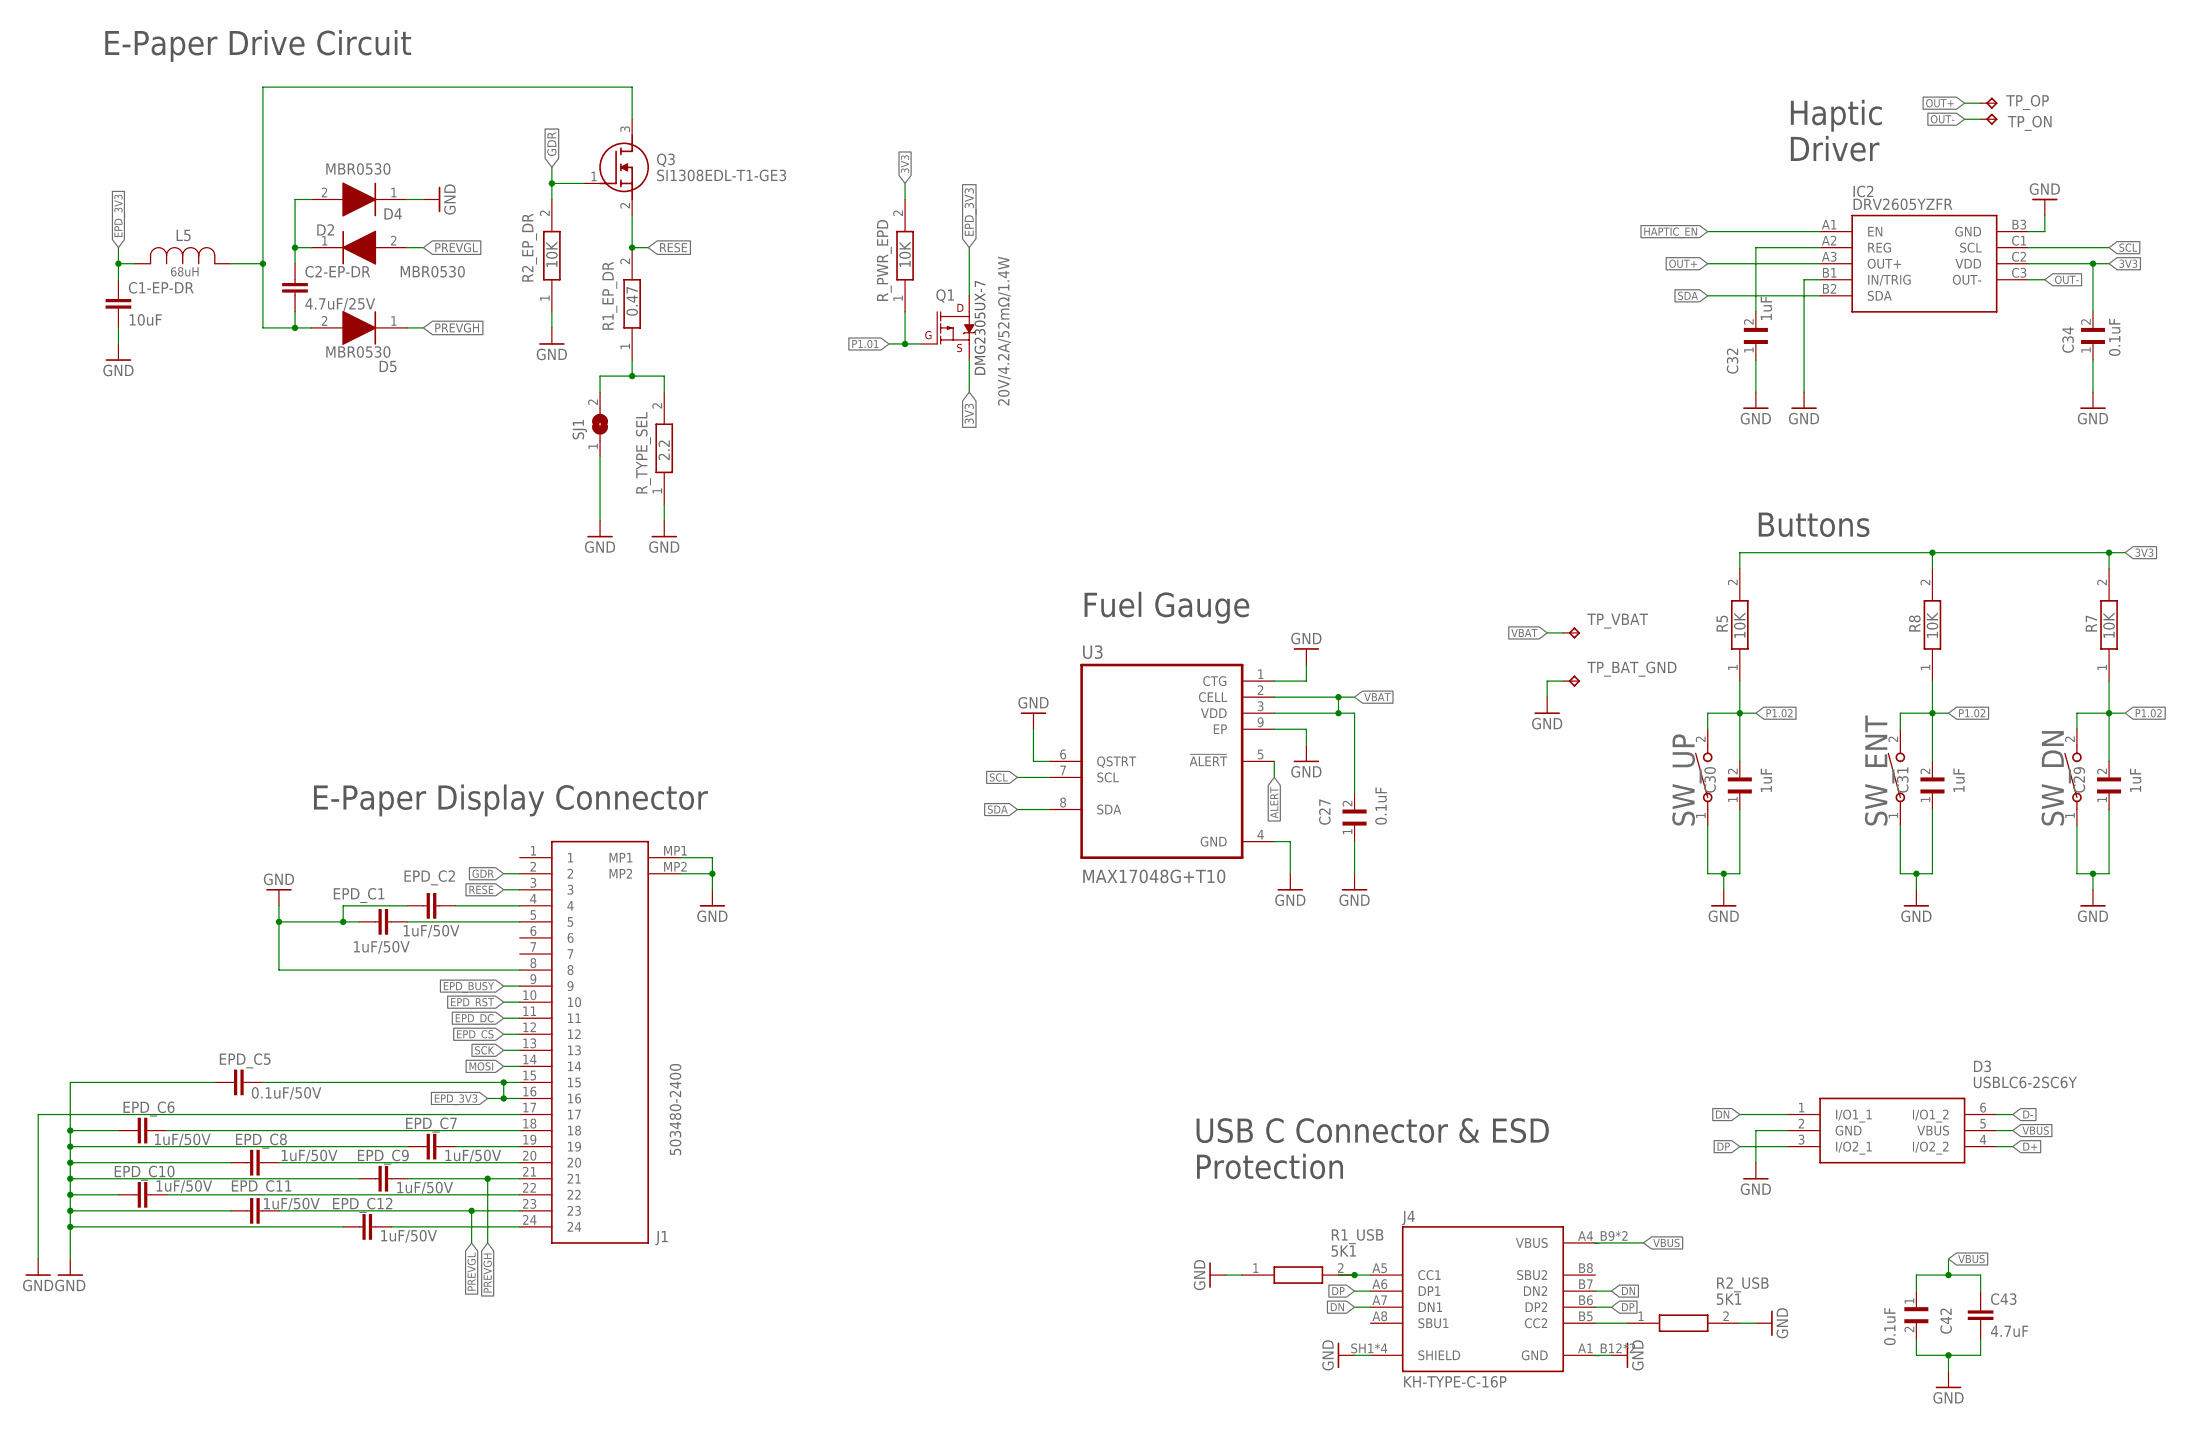
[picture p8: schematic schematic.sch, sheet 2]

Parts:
C1-EP-DR: 10uF; NORDIC_NRF_3_RESC0402_L
C2-EP-DR: 4.7uF/25V; NORDIC_NRF_3_RESC0402_L
C27, C34: 0.1uF; GRM011R60J152KE01L_2_CAPC0201X13N
C29, C30, C31: 1uF; GRM011R60J152KE01L_1_0201
C32: 1uF; GRM011R60J152KE01L_2_CAPC0201X13N
C42: 0.1uF; GRM011R60J152KE01L_1_0201
C43: 4.7uF; PERFECT_0402_0402
D2, D4, D5: MBR0530; ESP32_C6_LIBRARY_5_SOD3716X135N
D3: USBLC6-2SC6Y; ESP32_C6_LIBRARY_3_SOT95P280X145-6N
EPD_C1, EPD_C2, EPD_C6, EPD_C7, EPD_C8, EPD_C9, EPD_C10, EPD_C11, EPD_C12: 1uF/50V; NORDIC_NRF_3_RESC0402_L
EPD_C5: 0.1uF/50V; NORDIC_NRF_3_RESC0402_L
IC2: DRV2605YZFR; DRV2605YZFR_BGA9C50P3X3_144X144X62
J1: 503480-2400; 503480-2400_5034802400
J4: KH-TYPE-C-16P; KH-TYPE-C-16P_KINGHELM_KH-TYPE-C-16P
L5: 68uH; ESP32_C6_LIBRARY_2_IND_4828-WE-TPC_WRE
Q1: 20V/4.2A/52mΩ/1.4W; ESP32_C6_LIBRARY_4_ESP32_C6_LIBRARY_4_ESP32_C6_LIBRARY_4_ES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
Q3: SI1308EDL-T1-GE3; ESP32_C6_LIBRARY_6_SOT65P210X110-3N
R1_EP_DR: 0.47; CPF0201D7K68C1_0201
R1_USB, R2_USB: 5K1; CPF0201D7K68C1_0201
R2_EP_DR, R5, R7, R8: 10K; CPF0201D7K68C1_0201
R_PWR_EPD: 10K; CPF0201D7K68C1_0201
R_TYPE_SEL: 2.2; CPF0201D7K68C1_0201
SJ1: ESP32_C6_LIBRARY_7_JUMPER_SJ
SW_DN: 2025-10-22_07-23-44_LIBRARY_EVP-AKE31ASW_EVP-AKE3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; 2025-10-22_07-23-44_LIBRARY_SW_EVP-AKE31A_PAN
SW_ENT: 2025-10-22_07-23-44_LIBRARY_EVP-AKE31ASW_EVP-AKE3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; 2025-10-22_07-23-44_LIBRARY_SW_EVP-AKE31A_PAN
SW_UP: 2025-10-22_07-23-44_LIBRARY_EVP-AKE31ASW_EVP-AKE3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; 2025-10-22_07-23-44_LIBRARY_SW_EVP-AKE31A_PAN
TP_BAT_GND: HECTOR_WATCH_1_TPTP20R; HECTOR_WATCH_1_TP20R
TP_ON: HECTOR_WATCH_1_TPTP20R; HECTOR_WATCH_1_TP20R
TP_OP: HECTOR_WATCH_1_TPTP20R; HECTOR_WATCH_1_TP20R
TP_VBAT: HECTOR_WATCH_1_TPTP20R; HECTOR_WATCH_1_TP20R
U3: MAX17048G+T10; ESP32_C6_LIBRARY_SON50P200X200X80-9N

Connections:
3V3: C34.2, IC2.C2 (VDD), Q1.2 (S), R5.2, R7.2, R8.2, R_PWR_EPD.2; also elsewhere on the board
ALERT: U3.5 (!ALERT); also elsewhere on the board
D+: D3.4 (I/O2_2); also elsewhere on the board
D-: D3.6 (I/O1_2); also elsewhere on the board
DN: D3.1 (I/O1_1), J4.A7 (DN1), J4.B7 (DN2)
DP: D3.3 (I/O2_1), J4.A6 (DP1), J4.B6 (DP2)
EPD_3V3: C1-EP-DR.1, EPD_C5.2, J1.15, J1.16, L5.2, Q1.3 (D)
EPD_BUSY: J1.9; also elsewhere on the board
EPD_CS: J1.12; also elsewhere on the board
EPD_DC: J1.11; also elsewhere on the board
EPD_RST: J1.10; also elsewhere on the board
GDR: J1.2, Q3.1 (G), R2_EP_DR.2
GND: C1-EP-DR.2, C27.1, C29.1, C30.1, C31.1, C32.1, C34.1, C42.2, C43.2, D3.2 (GND), D4.1 (K), EPD_C1.1, EPD_C2.1, EPD_C5.1, EPD_C6.1, EPD_C7.1, EPD_C8.1, EPD_C9.1, EPD_C10.1, EPD_C11.1, EPD_C12.1, IC2.B1 (IN/TRIG), IC2.B3 (GND), J1.8, J1.17, J1.MP1, J1.MP2, J4.A1_B12 (GND), J4.A12_B1 (GND), J4.SH1 (SHIELD), J4.SH2 (SHIELD), J4.SH3 (SHIELD), J4.SH4 (SHIELD), R1_USB.1, R2_EP_DR.1, R2_USB.2, R_TYPE_SEL.1, SJ1.1, SW_DN.1, SW_ENT.1, SW_UP.1, TP_BAT_GND.TP, U3.1 (CTG), U3.4 (GND), U3.6 (QSTRT), U3.9 (EP); also elsewhere on the board
HAPTIC_EN: IC2.A1 (EN); also elsewhere on the board
MOSI: J1.14; also elsewhere on the board
unnamed: C2-EP-DR.2, D5.2 (A), L5.1, Q3.3 (D)
unnamed: C2-EP-DR.1, D2.1 (K), D4.2 (A)
unnamed: R1_EP_DR.1, R_TYPE_SEL.2, SJ1.2
unnamed: EPD_C2.2, J1.4
unnamed: EPD_C7.2, J1.19
unnamed: EPD_C1.2, J1.5
unnamed: C32.2, IC2.A2 (REG)
unnamed: EPD_C12.2, J1.24
unnamed: J4.B5 (CC2), R2_USB.1
unnamed: EPD_C8.2, J1.20
unnamed: EPD_C10.2, J1.22
unnamed: EPD_C6.2, J1.18
unnamed: J4.A5 (CC1), R1_USB.2
OUT+: IC2.A3 (OUT+), TP_OP.TP
OUT-: IC2.C3 (OUT-), TP_ON.TP
P1.01: Q1.1 (G), R_PWR_EPD.1; also elsewhere on the board
P1.02: C29.2, C30.2, C31.2, R5.1, R7.1, R8.1, SW_DN.2, SW_ENT.2, SW_UP.2; also elsewhere on the board
PREVGH: D5.1 (K), EPD_C9.2, J1.21
PREVGL: D2.2 (A), EPD_C11.2, J1.23
RESE: J1.3, Q3.2 (S), R1_EP_DR.2
SCK: J1.13; also elsewhere on the board
SCL: IC2.C1 (SCL), U3.7 (SCL); also elsewhere on the board
SDA: IC2.B2 (SDA), U3.8 (SDA); also elsewhere on the board
VBAT: C27.2, TP_VBAT.TP, U3.2 (CELL), U3.3 (VDD); also elsewhere on the board
VBUS: C42.1, C43.1, D3.5 (VBUS), J4.A4_B9 (VBUS), J4.A9_B4 (VBUS); also elsewhere on the board

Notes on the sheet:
E-Paper Drive Circuit
DMG2305UX-7
E-Paper Display Connector
Haptic Driver
Buttons
USB C Connector & ESD Protection
Fuel Gauge

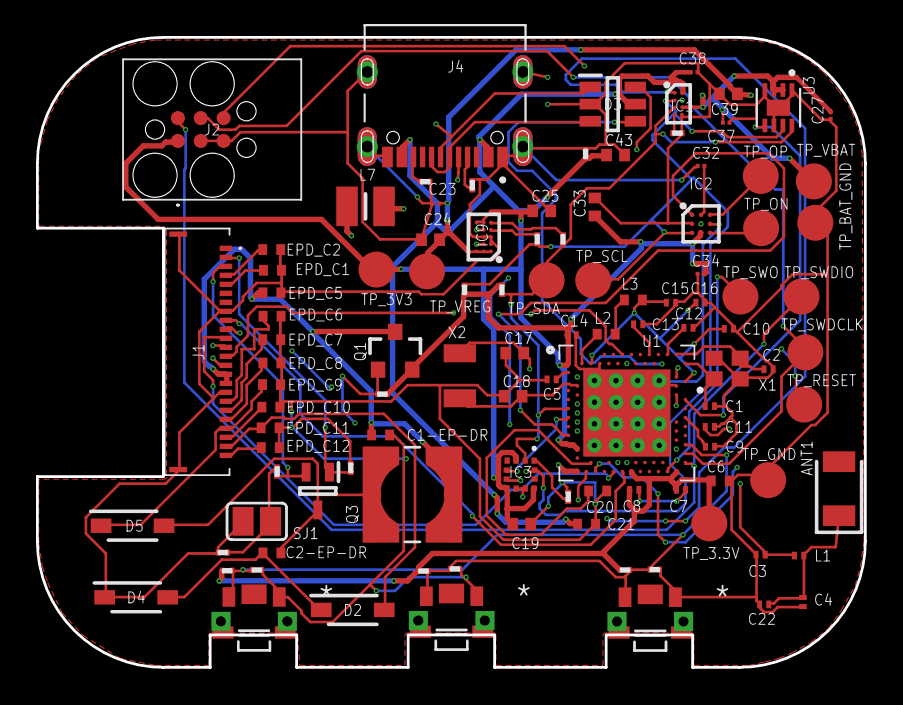
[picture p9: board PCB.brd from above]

Board: 4 copper layers, 46.0 x 35.0 mm, 105 parts (0 on the bottom side), 69 nets.

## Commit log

2026-04-10 Add PCB
    [PnP_proiect-tsc_front.csv, WearAwareNewCase.f3z, bill-of-materials.csv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]
2026-04-18 Revise BOM with detailed components and notes
    Updated the Bill of Materials section to include detailed components, descriptions, packages, quantities, and links for each item. Added passive components and notes regarding assembly and budgeting.
2026-04-18 update project files and rename hardware assets
    [PCB.brd, PnP_InkTime_front.csv, PnP_proiect-tsc_front.csv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]

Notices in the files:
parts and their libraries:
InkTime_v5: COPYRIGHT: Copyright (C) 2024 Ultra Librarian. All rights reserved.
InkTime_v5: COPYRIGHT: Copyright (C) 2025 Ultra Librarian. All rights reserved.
